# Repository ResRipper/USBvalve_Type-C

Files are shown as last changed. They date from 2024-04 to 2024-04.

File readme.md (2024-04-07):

# USB Valve - Type-C

Modified from Cecio's [USBvalve-1.2_A PCB](https://github.com/cecio/USBvalve/blob/main/PCB/Gerber_USBvalve-1.2_A-PCB.zip)

This repo only contains information about the board itself, please check [USBvalve](https://github.com/cecio/USBvalve) for more information.

## BOM

| PN | Vendor | Discription |
| --- | --- | --- |
| RP2040-Zero | Waveshare | A smaller version of the Raspberry Pi Pico with Type-C |
| HS91L02W2C01 | HS | 128x32 I2C OLED display |
| HB-PH3-25414PB2GOP | HANBO | 1x4 P2.54mm pin |
| USB-231-BRW | XUNPU | USB A port |
| [DISP-support](./DISP-support.step) | | 3D printed part to hold the OLED module |

## Assemble

1. Solder the RP2040-Zero to the bottom of the board

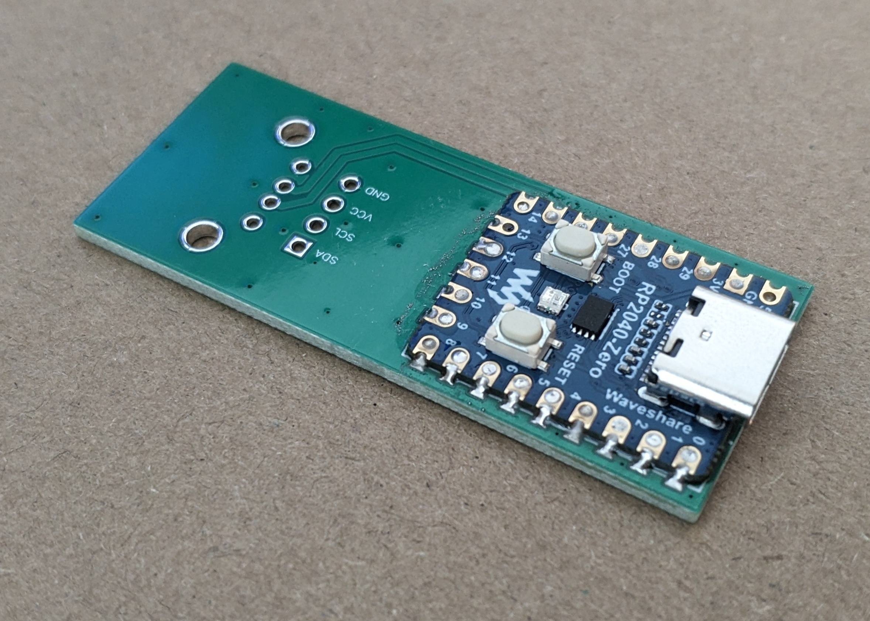
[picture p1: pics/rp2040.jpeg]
RP2040
    

2. Print out the [DISP-support](./DISP-support.step)

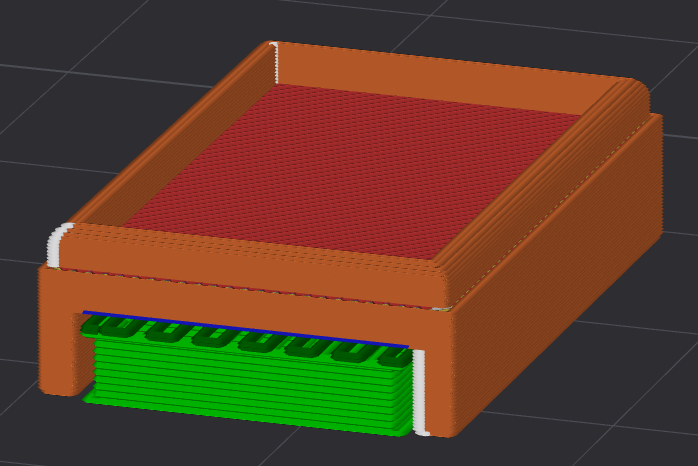
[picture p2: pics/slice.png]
slice
    

3. Press fit the printed part onto the PCB

    - U side facing up
    - Might require some force

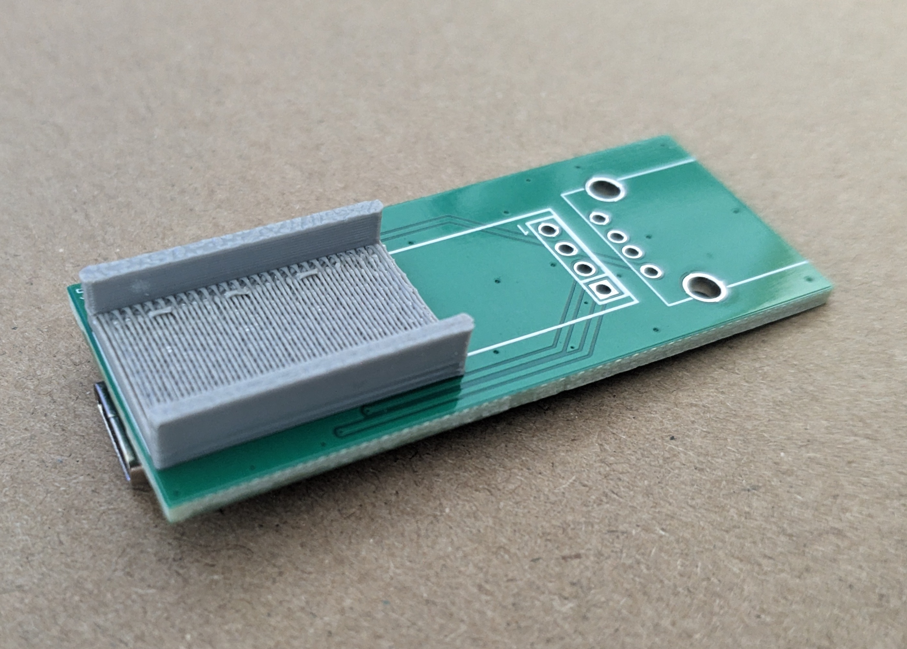
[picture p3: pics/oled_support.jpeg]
    

4. Assemble the pin and OLED module as shown in the photo, and solder them together

    - Cut the extra length if you like

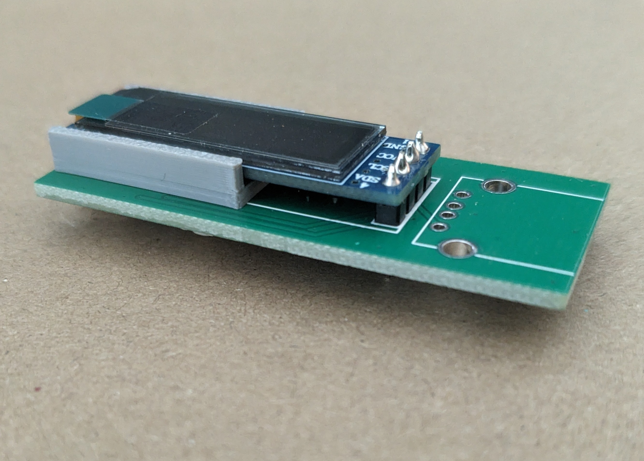
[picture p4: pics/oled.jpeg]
    

5. Solder the USB A port to the board

6. Make sure everything is properly connected and not short with a multi-meter before powering on

1. Load the latest [release (USBvalve-*-32.uf2)](https://github.com/cecio/USBvalve/releases) to the RP2040-Zero

Now you're done! Enjoy!

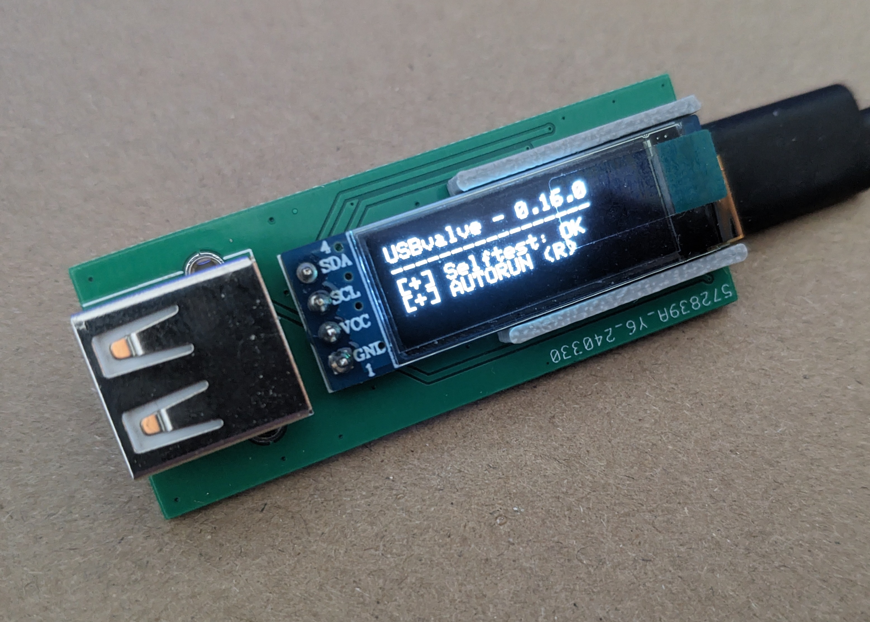
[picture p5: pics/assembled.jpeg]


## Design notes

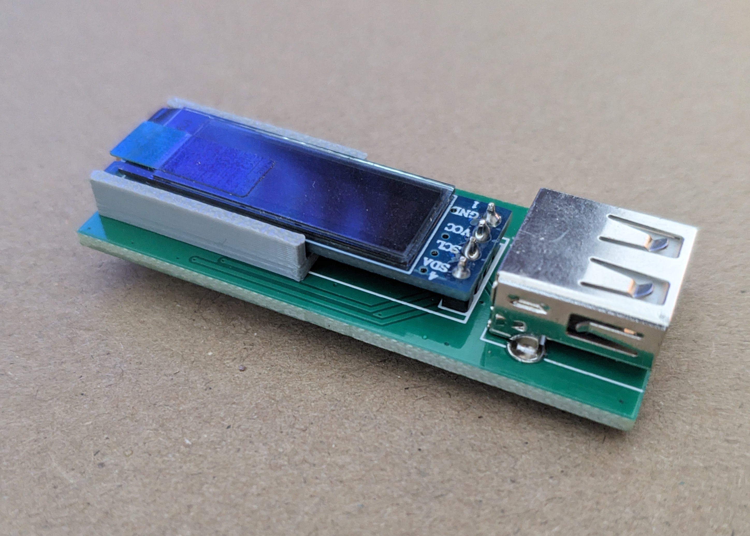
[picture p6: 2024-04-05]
pics/usb.jpeg

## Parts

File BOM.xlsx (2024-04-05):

No. | Quantity | Comment | Designator | Footprint | Value | Manufacturer Part | Manufacturer | Supplier Part | Supplier
1 | 1 | HS91L02W2C01 | OLED1 | OLED-TH_L38.0-W12.0_HS91L02W2C01 |  | HS91L02W2C01 | HS | C5248081 | LCSC
2 | 1 | RP2040-Zero | U1 | COMM-SMD_RP2040-ZERO |  | RP2040-Zero | Waveshare | C5350143 | LCSC
3 | 1 | HB-PH3-25414PB2GOP | U2 | HDR-TH_4P-P2.54-V-M |  | HB-PH3-25414PB2GOP | HANBO | C6332197 | LCSC
4 | 1 | USB-231-BRW | USB2 | USB-A-TH_USB-231-ARY |  | USB-231-BRW | XUNPU | C720526 | LCSC

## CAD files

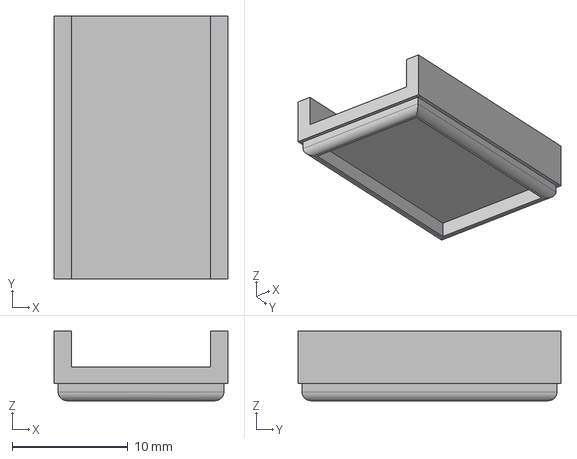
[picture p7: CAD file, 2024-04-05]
DISP-support.step
15.0 x 22.7 x 6.00 mm

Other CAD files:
DISP-support.FCStd

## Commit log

2024-04-05 Add BOM
    [BOM.xlsx]
2024-04-05 Add OLED display support part
    [DISP-support.FCStd, DISP-support.step]
2024-04-05 Add Gerber files
    [Drill_PTH_Through.DRL, Drill_PTH_Through_Via.DRL, Gerber_BoardOutlineLayer.GKO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]
2024-04-05 Create simple document
    - BOM
    - Assemble
